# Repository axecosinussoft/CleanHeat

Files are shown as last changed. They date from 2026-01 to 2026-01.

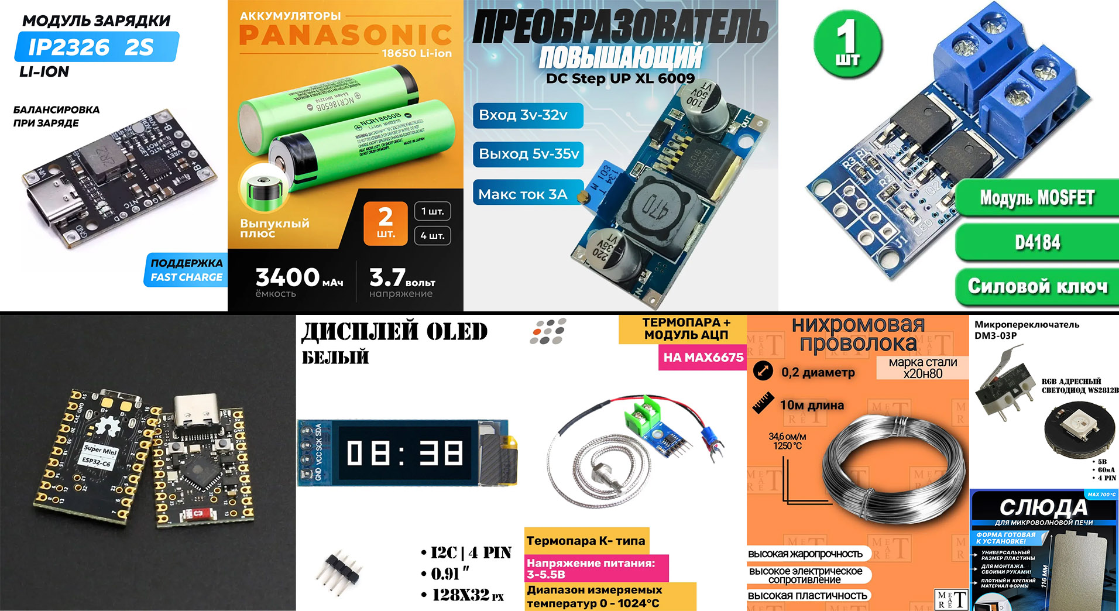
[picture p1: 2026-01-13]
1. 3D Models/1.2 MVP-3 (Jazz)/1.2.3 MVP-3 (Jazz) — Components.jpg

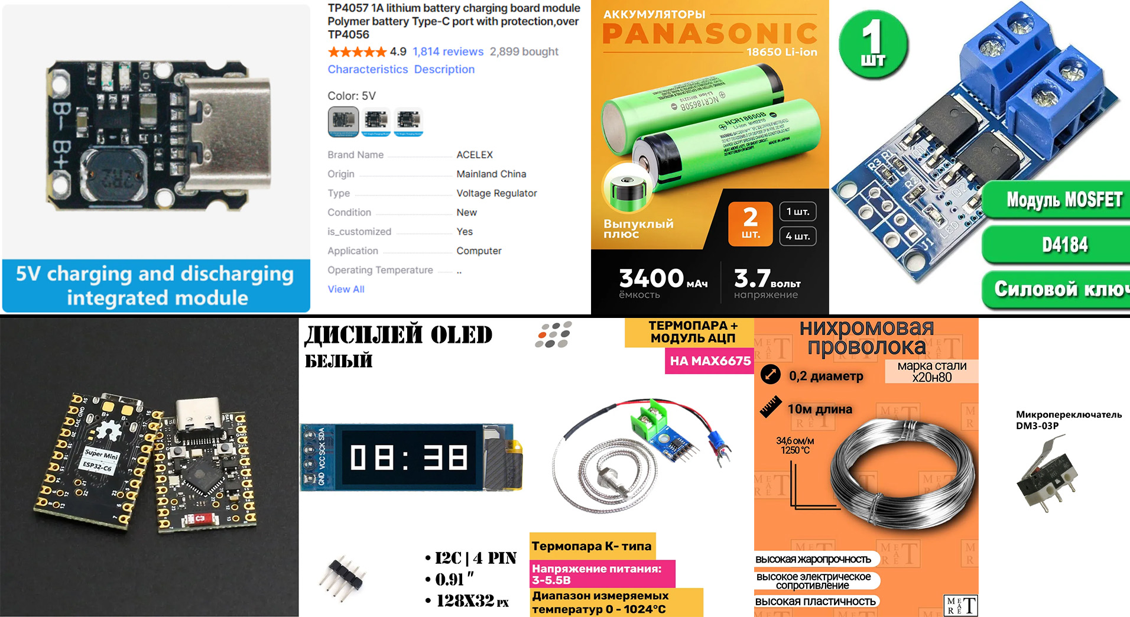
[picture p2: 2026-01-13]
1. 3D Models/1.1 MVP-2 (Slider)/1.1.3 MVP-2 (Slider) — Components.jpg

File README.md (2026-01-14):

Make your own PID controller for heating elements with PWM control and thermocouple feedback, advanced web interface, and smart backlighting.

Tutorial

https://habr.com/ru/articles/973106/

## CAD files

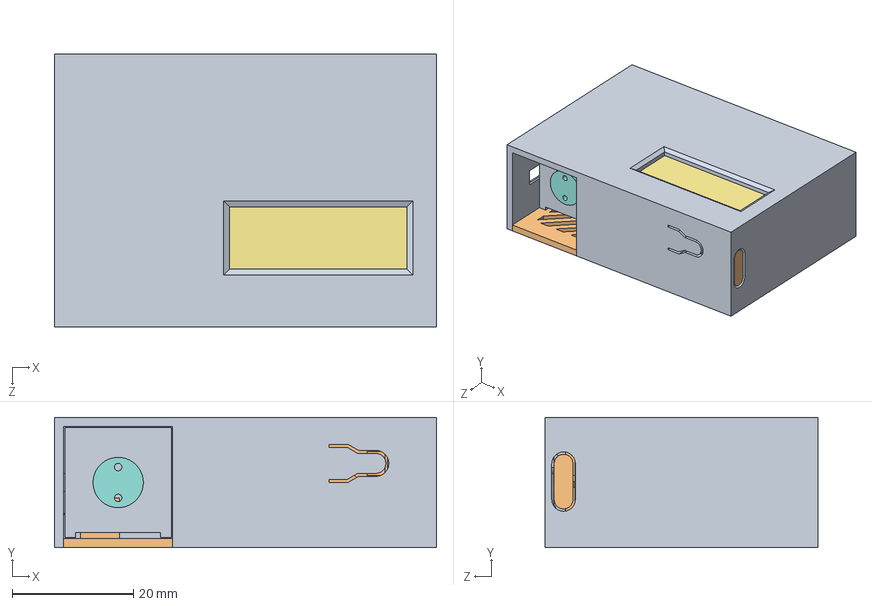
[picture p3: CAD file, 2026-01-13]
1. 3D Models/1.1 MVP-2 (Slider)/1.1.1 3D-Models — SolidWorks 2019/Сборка Clean Heat V7 Charge OLED MAX.SLDASM
63.0 x 21.5 x 45.0 mm
1. Корпус
ESP32-C3-Zero
Battery 16340
Модуль Micro зарядки Type С
MOSFET
MAX6675
OLED 128x32
Патрон нити
2. Каретка патрона
3. Корпус крышка
Кнопка small

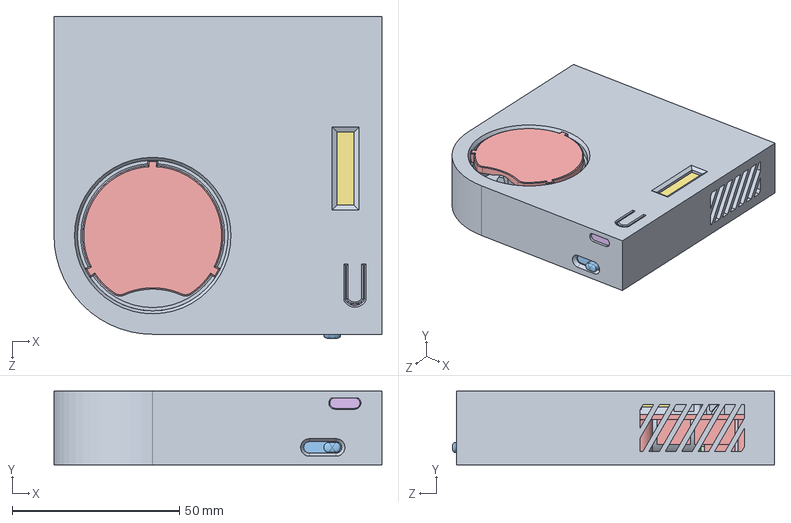
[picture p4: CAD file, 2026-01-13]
1. 3D Models/1.2 MVP-3 (Jazz)/1.2.1 3D-Models — SolidWorks 2019/Сборка Clean Heat V10 — 2S.SLDASM
98.0 x 22.0 x 96.3 mm
1. Корпус
2. Пластина-фиксатор колпака
2.2 Пластина-фиксатор колпака
Колпак
Wire1 x 3
Wire2 x 9
Wire3 x 2
Wire4
Battery 18650 x 2
MAX6675
MOSFET
Charger 2S IP2326
XL6019
ESP32-C3-Zero
OLED 128x32
Кнопка small
3. Подставка микрика
4. Переключатель питания
5. Крышка
LED_WS2812
6. Фиксатор ESP

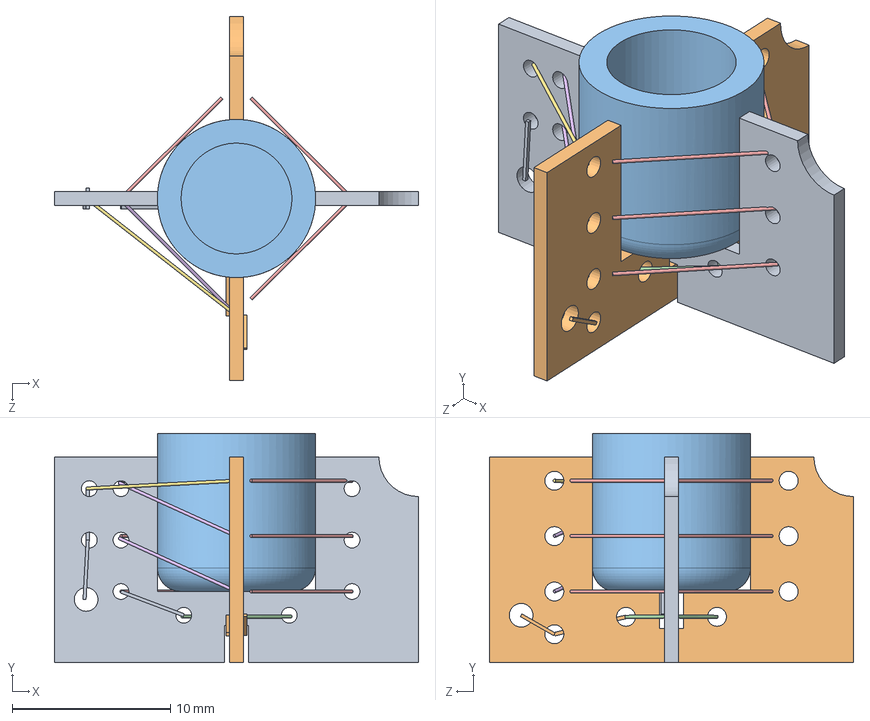
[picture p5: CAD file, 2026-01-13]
1. 3D Models/1.2 MVP-3 (Jazz)/1.2.1 3D-Models — SolidWorks 2019/1. Детали/0.1 Сборка патрона под колпак.SLDASM
23.0 x 14.5 x 23.0 mm
2. Пластина-фиксатор колпака
2.2 Пластина-фиксатор колпака
Колпак
Wire1 x 3
Wire2 x 9
Wire3 x 2
Wire4

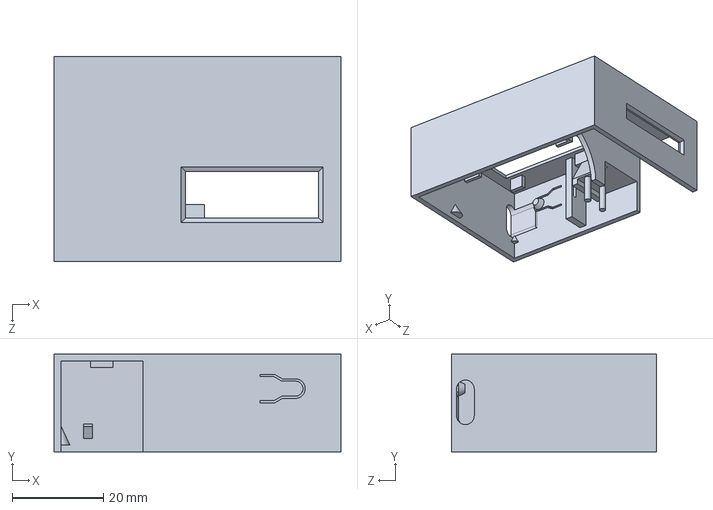
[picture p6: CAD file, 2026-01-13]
1. 3D Models/1.1 MVP-2 (Slider)/1.1.1 3D-Models — SolidWorks 2019/1. Детали/1. Корпус.SLDPRT
63.0 x 21.5 x 45.0 mm

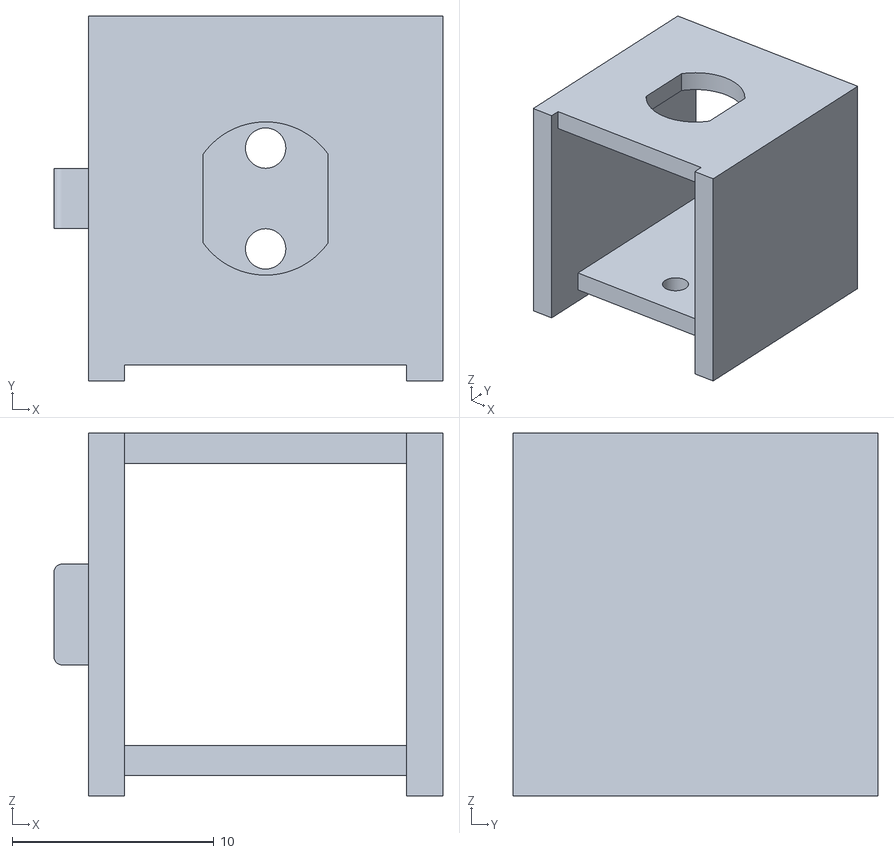
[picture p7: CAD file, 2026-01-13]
1. 3D Models/1.1 MVP-2 (Slider)/1.1.2 3D-Print — STL/2. Каретка патрона — Black.STL
19.3 x 18.1 x 18.0

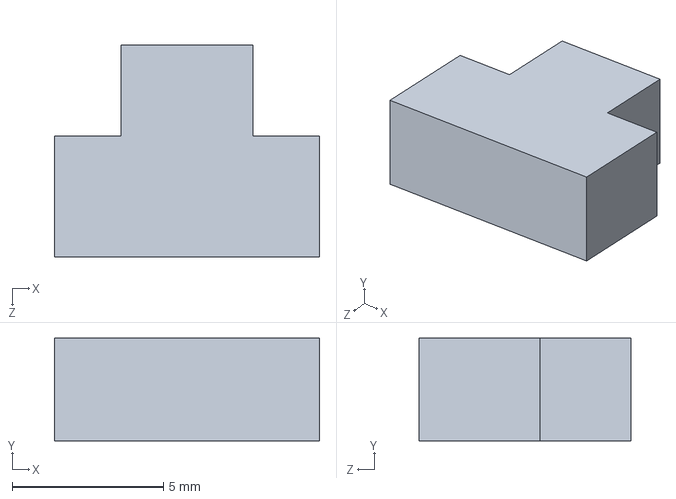
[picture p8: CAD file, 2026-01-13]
1. 3D Models/1.2 MVP-3 (Jazz)/1.2.1 3D-Models — SolidWorks 2019/1. Детали/6. Фиксатор ESP.SLDPRT
8.76 x 3.40 x 7.00 mm

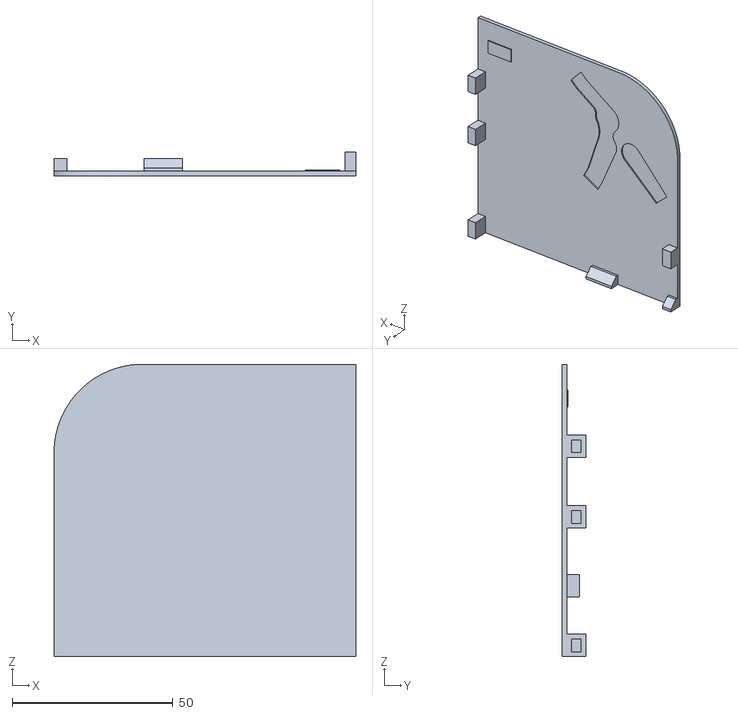
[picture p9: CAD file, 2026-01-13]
1. 3D Models/1.2 MVP-3 (Jazz)/1.2.2 3D-Print — STL/5. Крышка.STL
94.0 x 7.50 x 91.0

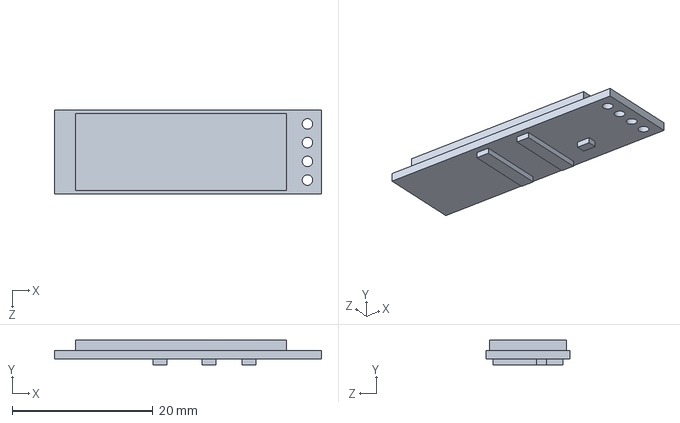
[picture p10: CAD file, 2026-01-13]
1. 3D Models/1.1 MVP-2 (Slider)/1.1.1 3D-Models — SolidWorks 2019/1. Детали/OLED 128x32.SLDPRT
38.0 x 3.50 x 12.0 mm

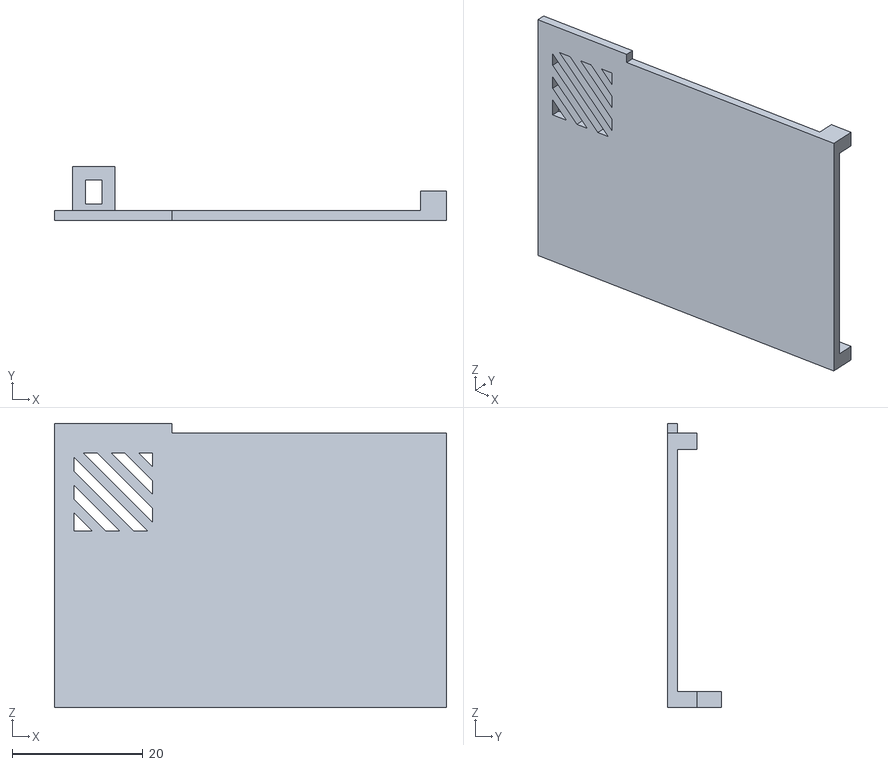
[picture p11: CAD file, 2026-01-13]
1. 3D Models/1.1 MVP-2 (Slider)/1.1.2 3D-Print — STL/3. Корпус крышка — Прозрачный.STL
60.0 x 8.20 x 43.5

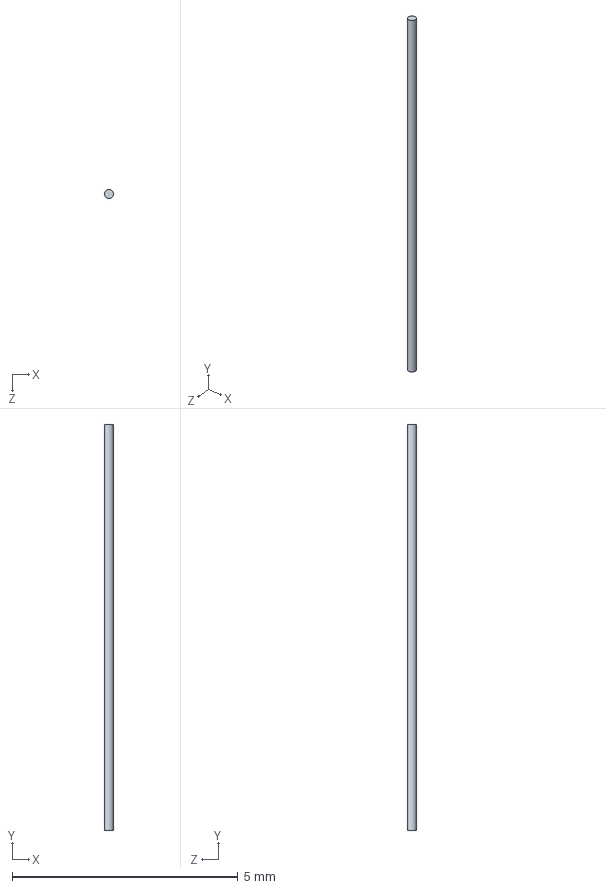
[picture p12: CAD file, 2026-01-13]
1. 3D Models/1.2 MVP-3 (Jazz)/1.2.1 3D-Models — SolidWorks 2019/1. Детали/Wire2.SLDPRT
0.2 x 9.00 x 0.2 mm

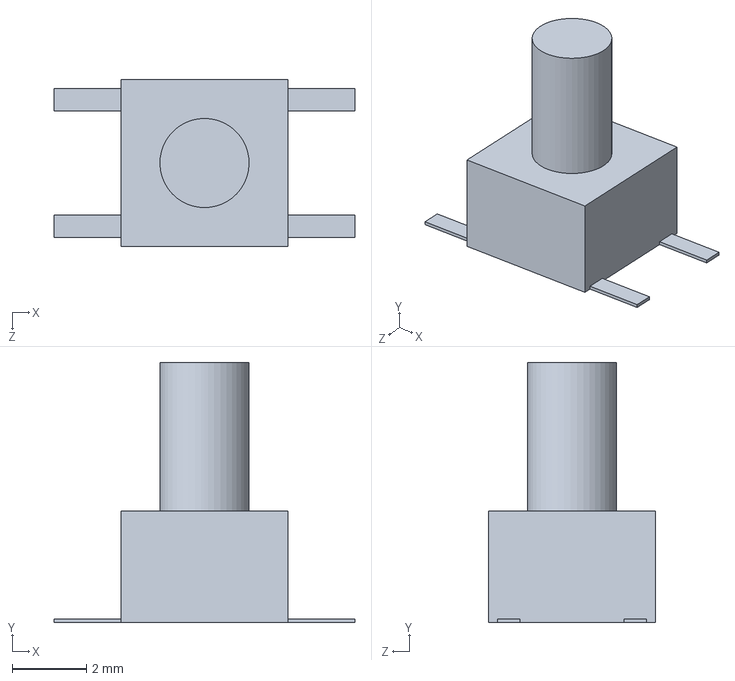
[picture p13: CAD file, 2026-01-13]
1. 3D Models/1.1 MVP-2 (Slider)/1.1.1 3D-Models — SolidWorks 2019/1. Детали/Button.SLDPRT
8.10 x 7.00 x 4.50 mm

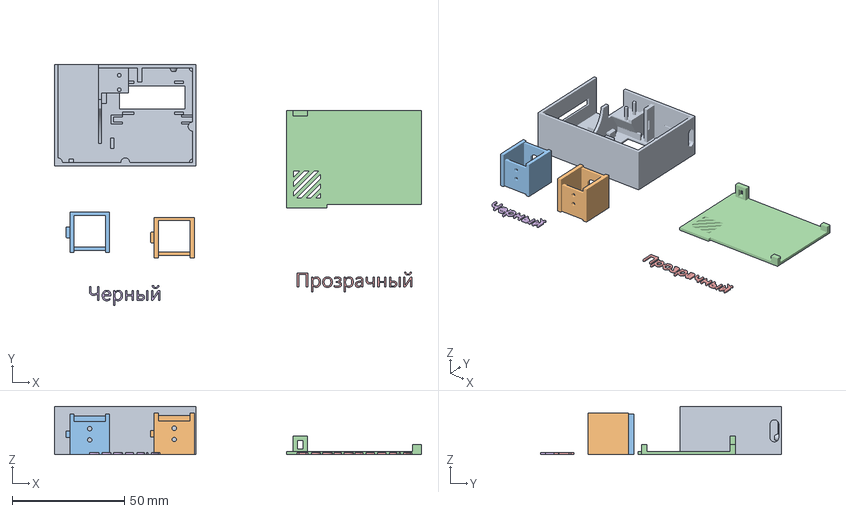
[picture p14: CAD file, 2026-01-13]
1. 3D Models/1.1 MVP-2 (Slider)/1.1.2 3D-Print — STL/2025.06.02 — V1.3mf
163.3 x 107.1 x 21.5 mm
1. Корпус.STL
2. Каретка патрона form.STL
2. Каретка патрона.STL
3. Корпус крышка.STL
Рельефный текст x 2

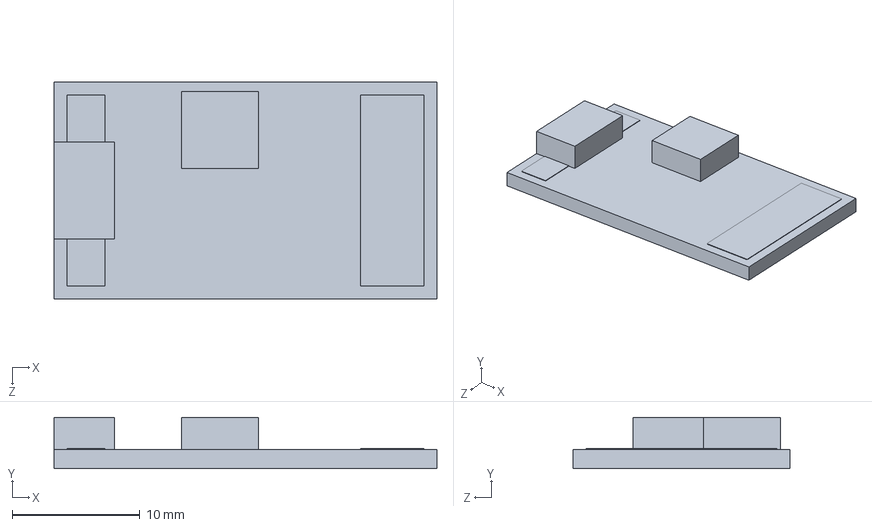
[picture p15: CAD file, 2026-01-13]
1. 3D Models/1.2 MVP-3 (Jazz)/1.2.1 3D-Models — SolidWorks 2019/1. Детали/Charger 2S IP2326.SLDPRT
30.0 x 4.00 x 17.0 mm

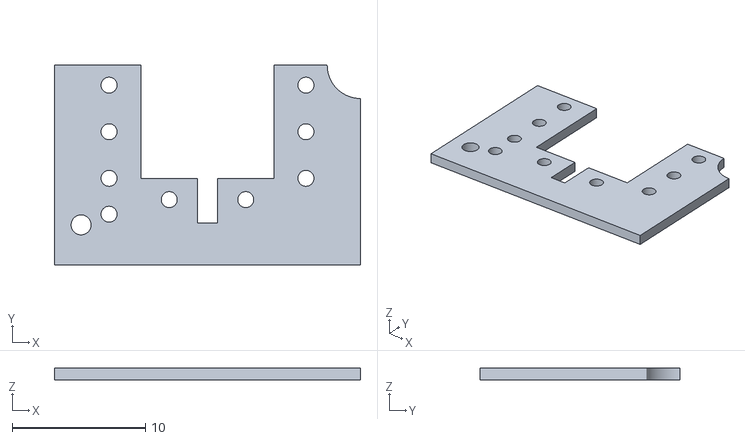
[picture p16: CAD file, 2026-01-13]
1. 3D Models/1.2 MVP-3 (Jazz)/1.2.2 3D-Print — STL/2.2 Пластина-фиксатор колпака.STL
23.0 x 15.0 x 0.9

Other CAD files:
1. 3D Models/1.2 MVP-3 (Jazz)/1.2.2 3D-Print — STL/6. Фиксатор ESP.STL
1. 3D Models/1.1 MVP-2 (Slider)/1.1.1 3D-Models — SolidWorks 2019/1. Детали/Модуль Micro зарядки Type С.SLDPRT
1. 3D Models/1.1 MVP-2 (Slider)/1.1.2 3D-Print — STL/2. Каретка патрона form — Black.STL
1. 3D Models/1.2 MVP-3 (Jazz)/1.2.1 3D-Models — SolidWorks 2019/1. Детали/Wire3.SLDPRT
1. 3D Models/1.1 MVP-2 (Slider)/1.1.1 3D-Models — SolidWorks 2019/1. Детали/2. Каретка патрона.SLDPRT
1. 3D Models/1.1 MVP-2 (Slider)/1.1.1 3D-Models — SolidWorks 2019/1. Детали/3. Корпус крышка.SLDPRT
1. 3D Models/1.1 MVP-2 (Slider)/1.1.1 3D-Models — SolidWorks 2019/1. Детали/Battery 14500.SLDPRT
1. 3D Models/1.1 MVP-2 (Slider)/1.1.1 3D-Models — SolidWorks 2019/1. Детали/Battery 16340.SLDPRT
1. 3D Models/1.1 MVP-2 (Slider)/1.1.1 3D-Models — SolidWorks 2019/1. Детали/ESP32-C3-Zero.SLDPRT
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

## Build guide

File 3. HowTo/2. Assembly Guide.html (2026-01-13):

# 🔥 Clean Heat Controller

Firmware v1.0.65 | Инструкция по сборке

## 📦 Список компонентов

ESP32-C3 Super Mini

Микроконтроллер с WiFi, 4MB Flash

OLED Дисплей 0.91"

128×32 пикселей, I2C (SSD1306)

MAX6675 + K-термопара

Модуль АЦП для термопары, 0-1024°C

MOSFET D4184

Силовой ключ для нагревателя

TP4056/TP4057 модуль

Зарядка Li-ion через Type-C

2× 18650 Panasonic

Li-ion 3400mAh, соединены последовательно

Нихромовая проволока

0.2мм, X20H80, нагревательный элемент

WS2812B LED

Адресный RGB светодиод

Микропереключатель

DM3-03P, кнопка управления

Резисторы

100K + 56K (делитель напряжения)

## 📐 Схема подключения

Принципиальная схема Clean Heat Controller

## 🔌 Таблица подключений

ESP32-C3 Pin | Подключение | Функция | Цвет провода
GPIO0 | MAX6675 → DO | SPI Data Out (термопара) | Зелёный
GPIO1 | MAX6675 → CS | SPI Chip Select | Оранжевый
GPIO2 | MAX6675 → CLK | SPI Clock | Фиолетовый
GPIO3 | Делитель напряжения | ADC измерение батареи | Голубой
GPIO4 | MOSFET D4184 → SIG | PWM управление нагревателем | Красный
GPIO6 | OLED → SDA | I2C Data | Красный
GPIO7 | OLED → SCL | I2C Clock | Синий
GPIO8 | WS2812B → DIN | Адресный LED данные | Зелёный
GPIO9 | Кнопка → SIG | Вход кнопки (INPUT_PULLUP) | Сиреневый
3V3 | MAX6675, OLED, WS2812B → VCC | Питание 3.3В | Красный
GND | Все модули → GND | Общая земля | Чёрный

## 🔧 Делитель напряжения

## 📝 Пошаговая сборка

1 Подготовка батарейного отсека

Соедините два аккумулятора 18650 последовательно (+ первого к - второго). Общее напряжение: 6.0-8.4В.

2 Делитель напряжения

Спаяйте резисторы 100K и 56K последовательно. Точка соединения идёт на GPIO3. Верхний конец (100K) к B+, нижний (56K) к GND.

3 MAX6675 термопара

Подключите модуль: DO→GPIO0, CS→GPIO1, CLK→GPIO2, VCC→3V3, GND→GND. Припаяйте термопару к модулю.

4 OLED дисплей

Подключите по I2C: SDA→GPIO6, SCL→GPIO7, VCC→3V3, GND→GND.

5 MOSFET и нагреватель

SIG→GPIO4, VCC модуля→B+ батареи, GND→GND. Выход MOSFET (OUT+/OUT-) к нихромовой проволоке.

6 WS2812B LED

DIN→GPIO8, VCC→3V3, GND→GND.

7 Кнопка управления

Один контакт→GPIO9, второй→GND. Внутренний pull-up включён в коде.

8 Зарядка TP4056

B+→плюс батареи, B-→минус батареи. Модуль обеспечивает зарядку через Type-C.

⚠️ Важные предупреждения

• Перед первым включением проверьте все соединения мультиметром
• Не замыкайте выходы батареи — риск возгорания
• Нихромовая проволока нагревается до 350°C — соблюдайте осторожность
• Не оставляйте устройство без присмотра во время нагрева

💡 Рекомендации

• Используйте провода сечением минимум 22AWG для силовых цепей
• Термопару располагайте максимально близко к нагревателю
• Обеспечьте теплоотвод для MOSFET при длительной работе
• Перед прошивкой отключите питание от батареи

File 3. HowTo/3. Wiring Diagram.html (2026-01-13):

# Clean Heat Controller

Схема подключения компонентов

VCC / V+ / 3V3 / VIN

GND

DO / DIN / ADC

CS / SDA

CLK / SCL

PWM / SIG / OUT

Button

### Таблица подключений

GPIO 0MAX6675 DO

GPIO 1MAX6675 CS

GPIO 2MAX6675 CLK

GPIO 3Battery ADC (Divider)

GPIO 4MOSFET PWM

GPIO 6OLED SDA

GPIO 7OLED SCL

GPIO 8WS2812B DIN

GPIO 9Button → GND

3V3Logic VCC (3.3V)

VINBattery Input (7.4V)

GNDCommon Ground

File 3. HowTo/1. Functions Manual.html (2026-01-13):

# Clean Heat Controller

Руководство по функциям и управлению • Версия прошивки 1.0.63

## Обзор устройства

Clean Heat Controller — температурный контроллер на базе ESP32-C3 с PID-регулированием, веб-интерфейсом и RGB индикацией. Устройство предназначено для точного управления нагревательными элементами.

PID-регулирование

Адаптивный алгоритм с агрессивным и консервативным режимами для точного поддержания температуры

WiFi управление

Встроенная точка доступа с captive portal и веб-интерфейсом

Мониторинг АКБ

Отслеживание напряжения и процента заряда 2S Li-ion аккумулятора

RGB индикация

Цветовая индикация режимов, температуры и состояния

## Управление кнопкой

Одиночное нажатие

Переключение температурного режима: OFF → Mode 1 → Mode 2 → Mode 3 → MAX → OFF. При пользовательском режиме (PWM или Custom Temp) — переход в OFF.

Двойное нажатие

Переключение режима LED: OFF → TEMP → FLOW → OFF. На экране появляется уведомление о текущем режиме.

Тройное нажатие

Управление таймером: пауза таймера (если запущен) или сброс (если на паузе). Таймер мигает при действии.

Долгое нажатие (1 сек)

Переход в режим ожидания сна. Экран инвертируется, полоска внизу анимированно уменьшается. Нагрев отключается, LED выключается. Если не нажать кнопку в течение 5 секунд — устройство уйдёт в глубокий сон.

## Температурные режимы

Режим | Температура | Описание
OFF | — | Нагрев выключен, PWM = 0%
Mode 1 | 210°C * | Первый предустановленный режим
Mode 2 | 220°C * | Второй предустановленный режим
Mode 3 | 240°C * | Третий предустановленный режим
MAX | 100% PWM | Максимальная мощность без регулирования

* Настраиваемые значения
Температуры режимов Mode 1, Mode 2, Mode 3 можно изменить через веб-интерфейс. Значения сохраняются в энергонезависимой памяти. Диапазон: 50–350°C. По умолчанию: 210 / 220 / 240°C.

### Дополнительные режимы (через веб-интерфейс)

Режим | Описание
Custom Temp | Произвольная температура с PID-регулированием (кнопки ±1°C и ±5°C)
Custom PWM | Прямое управление мощностью 0–100% без PID-регулирования

## Дисплей

Дисплей SSD1306 128×32 пикселей в портретной ориентации отображает всю ключевую информацию:

### Элементы дисплея

Целевая температура Инвертированный блок с текущим режимом

Текущая температура Значение с термопары в °C

PWM мощность OFF или 0–100%

Счётчик циклов Количество завершённых сессий нагрева

WiFi индикатор Точка внизу = клиент подключен

Таймер MM:SS с момента начала нагрева

Линия предупреждения Анимированно исчезает перед сном

## LED индикация

LED OFF

Светодиод выключен

LED TEMP

Цвет отражает температуру или PWM:
Синий → Зелёный → Жёлтый → Оранжевый → Красный → Розовый
В режиме MAX — пульсация красный/оранжевый

LED FLOW

Плавная радужная анимация с периодическими вспышками. Параметры настраиваются через Serial.

### Специальные состояния LED

Загрузка устройства Радужная анимация 1.7 сек

Вкладка Update активна Плавная пульсация синий ↔ фиолетовый

OTA обновление Мигание красный / синий

OTA успешно Фиолетовые вспышки → перезагрузка

## WiFi и веб-интерфейс

### Подключение

Имя сети (SSID) Clean Heat

Пароль Отсутствует (открытая сеть)

Captive Portal Автоматическое перенаправление

### Функции веб-интерфейса

Управление режимами

Быстрые кнопки OFF / Mode 1 / Mode 2 / Mode 3 / MAX

Точная настройка температуры

Кнопки ±1°C и ±5°C для пользовательской температуры

PWM управление

Слайдер 0–100% для прямого управления мощностью

Сохранение режимов

Запись текущей температуры в Mode 1/2/3

Управление таймером

Пауза и сброс таймера сессии

Счётчик циклов

Просмотр, коррекция (±1) и сброс счётчика

Мониторинг

Температура, PWM, напряжение АКБ в реальном времени

OTA обновление

Загрузка новой прошивки через браузер

Темы оформления

Светлая и тёмная тема интерфейса

## API эндпоинты

GET /status JSON со всеми параметрами устройства

GET /set_temp?mode=0-4 Установка режима (0=OFF, 1-3=Mode, 4=MAX)

GET /adjust_temp?delta=±N Изменение температуры на N градусов

GET /set_pwm?value=0-100 Установка PWM в процентах

GET /pwm_adjust?delta=±N Изменение PWM на N процентов

GET /save_mode_temp?mode=1-3 Сохранение текущей температуры в режим

GET /timer_pause Пауза/возобновление таймера

GET /timer_reset Сброс таймера

GET /cycle_adjust?delta=±1 Изменение счётчика циклов

GET /cycle_reset Сброс счётчика циклов

GET /set_led_mode?mode=0-2 Режим LED (0=OFF, 1=TEMP, 2=FLOW)

GET /toggle_led Переключение LED вкл/выкл

GET /set_theme?dark=true|false Установка темы интерфейса

POST /update OTA загрузка прошивки (multipart/form-data)

## Serial команды (LED Flow)

Настройка параметров режима LED FLOW через Serial Monitor (115200 baud):

flow_settings

Показать текущие настройки

flow_speed <10-200>

Скорость смены цвета радуги (по умолчанию: 50)

flow_pulse_min <3000-30000>

Минимальный интервал между вспышками в мс (по умолчанию: 5000)

flow_pulse_max <5000-60000>

Максимальный интервал между вспышками в мс (по умолчанию: 15000)

flow_pulse_duration <200-2000>

Длительность одной вспышки в мс (по умолчанию: 800)

flow_pulse_count <1-10>

Максимальное количество вспышек подряд (по умолчанию: 3)

flow_help

Справка по командам

## Автоматические функции

### Auto Sleep

Устройство автоматически переходит в режим ожидания сна если:

- Нагрев выключен
- Нет подключенных WiFi клиентов
- Прошло 30 секунд без активности (или 120 сек если LED включен)

### Счётчик циклов нагрева

Цикл засчитывается если:

- Нагрев был активен минимум 20 секунд
- Начальная температура была ниже 80°C (исключает "продолжение")

### PID-регулятор

Агрессивный режим (ошибка > 10°C) Kp=8.0, Ki=0.5, Kd=2.0

Консервативный режим (ошибка ≤ 10°C) Kp=3.0, Ki=0.2, Kd=1.0

Коррекция температуры +15°C к целевой (TEMP_CORRECTION)

Допуск стабильности ±2°C (TEMP_TOLERANCE)

## Технические параметры

### Питание

Напряжение АКБ 6.0 – 8.4V (2S Li-ion)

Делитель напряжения ×2.782

### Измерения

Обновление температуры Каждые 500 мс

Обновление напряжения Каждые 2000 мс (10 сэмплов)

Обновление PID Каждые 200 мс

### Управление

PWM частота 1000 Hz

PWM разрешение 8 бит (0-255)

Debounce кнопки 50 мс

Долгое нажатие 1000 мс

Таймаут двойного клика 500 мс

### Sleep

Предупреждение перед сном 5 секунд

Auto Sleep (LED выключен) 30 секунд

Auto Sleep (LED включен) 120 секунд

Clean Heat Controller v1.0.63 • Руководство по функциям

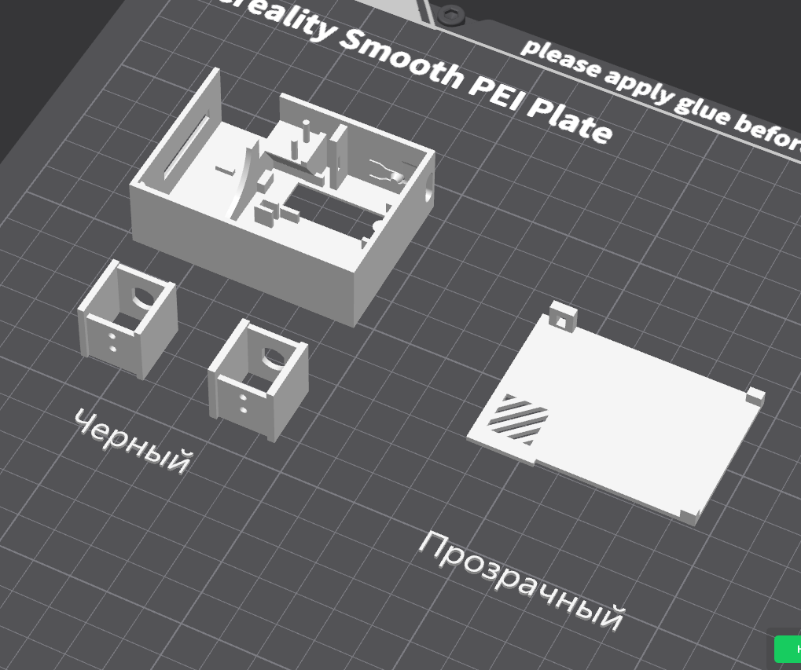
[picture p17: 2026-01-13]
1. 3D Models/1.1 MVP-2 (Slider)/1.1.2 3D-Print — STL/Place.png

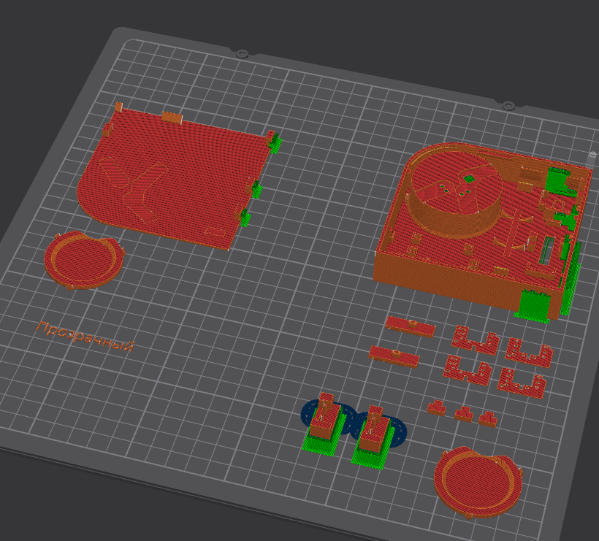
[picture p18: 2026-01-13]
1. 3D Models/1.2 MVP-3 (Jazz)/1.2.2 3D-Print — STL/2025.07.08 — V10 (2S).png

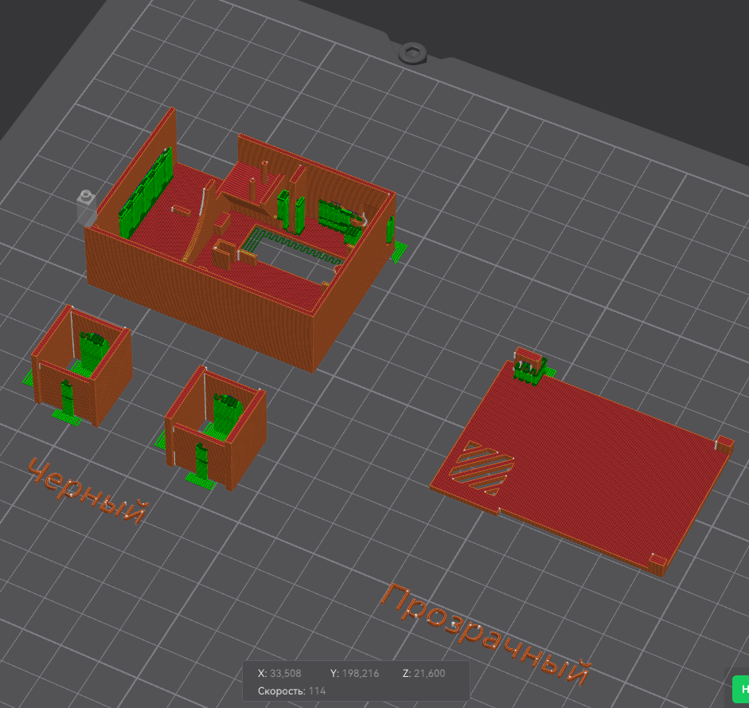
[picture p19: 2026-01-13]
1. 3D Models/1.1 MVP-2 (Slider)/1.1.2 3D-Print — STL/Поддержки.png

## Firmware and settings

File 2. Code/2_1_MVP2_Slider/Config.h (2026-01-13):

#ifndef CONFIG_H
#define CONFIG_H

#define FIRMWARE_VERSION "1.0.65"

extern int MODE_1_TEMP;
extern int MODE_2_TEMP;
extern int MODE_3_TEMP;

#define DEFAULT_MODE_1_TEMP 210
#define DEFAULT_MODE_2_TEMP 220
#define DEFAULT_MODE_3_TEMP 240

#define TEMP_CORRECTION 15.0

#define SCREEN_WIDTH 128
#define SCREEN_HEIGHT 32
#define SDA_PIN 6
#define SCL_PIN 7
#define SCREEN_ADDRESS 0x3C

#define MAX_CLK_PIN 2
#define MAX_CS_PIN  1
#define MAX_DO_PIN  0

#define BUTTON_PIN 9
#define HEATER_PIN 3
#define BATTERY_PIN 4

#define LED_PIN 8
#define NUM_LEDS 1
#define LED_BRIGHTNESS 200

#define PWM_FREQ 1000
#define PWM_RESOLUTION 8
#define PWM_CHANNEL 0

#define VOLTAGE_DIVIDER_FACTOR 3.15
#define ADC_REFERENCE_VOLTAGE 3.3
#define ADC_RESOLUTION 4095.0
#define BATTERY_MIN_VOLTAGE 3.0
#define BATTERY_MAX_VOLTAGE 4.2

#define VOLTAGE_FILTER_ALPHA 0.1
#define VOLTAGE_SAMPLES 10
#define VOLTAGE_SAMPLE_INTERVAL 10

#define TEMP_UPDATE_INTERVAL 500
#define VOLTAGE_UPDATE_INTERVAL 2000
#define DEBOUNCE_DELAY 50
#define INIT_DELAY 500
#define LONG_PRESS_DURATION 1000
#define DOUBLE_CLICK_TIMEOUT 500
#define FLASH_DURATION 100

#define PID_UPDATE_INTERVAL 200
#define TEMP_TOLERANCE 2.0

#define KP_AGGRESSIVE 8.0
#define KI_AGGRESSIVE 0.5
#define KD_AGGRESSIVE 2.0

#define KP_CONSERVATIVE 3.0
#define KI_CONSERVATIVE 0.2
#define KD_CONSERVATIVE 1.0

#define TEMP_GAP_THRESHOLD 10.0
#define INTEGRAL_WINDUP_LIMIT 50.0
#define DERIVATIVE_FILTER_ALPHA 0.3

#define SLEEP_WARNING_DURATION 5000
#define BATTERY_BLINK_INTERVAL 600
#define SCREEN_FLASH_DURATION 100
#define WAKE_BUTTON_BLOCK_TIME 500

#define AUTO_SLEEP_TIMEOUT 30000
#define AUTO_SLEEP_TIMEOUT_LED_ACTIVE 120000

#define CYCLE_COUNT_THRESHOLD 20000
#define CYCLE_CONTINUATION_TEMP_THRESHOLD 80.0

#define LED_FLOW_DEFAULT_SPEED 50
#define LED_FLOW_DEFAULT_PULSE_MIN_INTERVAL 5000
#define LED_FLOW_DEFAULT_PULSE_MAX_INTERVAL 15000
#define LED_FLOW_DEFAULT_PULSE_DURATION 800
#define LED_FLOW_DEFAULT_PULSE_COUNT 3

extern const char* ssid;
extern const byte DNS_PORT;

extern DNSServer dnsServer;
extern AsyncWebServer server;
extern Adafruit_SSD1306 display;
extern MAX6675 thermocouple;
extern Preferences prefs;

enum TempMode { TEMP_OFF, TEMP_200, TEMP_220, TEMP_240, TEMP_MAX };
extern TempMode currentTempMode;
extern bool isCustomPWM;
extern int customPWMValue;
extern int currentCustomTemp;

enum LEDMode { LED_OFF, LED_TEMP, LED_FLOW };
extern LEDMode currentLEDMode;

extern const float targetTemps[5];
extern const String tempLabels[5];

struct PIDData {
  float kp, ki, kd;
  float lastError;
  float integral;
  float lastTemp;
  float filteredDerivative;
  bool isStable;
  int stableCount;
  unsigned long lastTime;
};

extern PIDData pid;

extern float temperature;
extern float batteryVoltage;
extern float filteredVoltage;
extern int batteryPercent;

extern bool timerRunning;
extern bool timerPaused;
extern unsigned long timerStartMillis;
extern unsigned long timerPausedTime;
extern unsigned long timerElapsed;
extern unsigned long lastDisplayMillis;
extern bool timerFlashActive;
extern unsigned long timerFlashStart;
extern bool screenFlashActive;
extern unsigned long screenFlashStart;

extern int lastButtonState;
extern int buttonState;
extern unsigned long lastDebounceTime;
extern unsigned long buttonPressTime;
extern unsigned long buttonReleaseTime;
extern bool longPressHandled;
extern bool waitingForDoubleClick;
extern unsigned long firstClickTime;
extern int clickCount;
extern bool waitingForMultiClick;
extern unsigned long lastClickTime;

extern unsigned long previousTempMillis;
extern unsigned long previousVoltageMillis;
extern unsigned long voltageSampleMillis;
extern int voltageSampleIndex;
extern float voltageSampleSum;
extern bool voltageReadingActive;
extern unsigned long initStartTime;
extern bool isInitialized;

extern int pidOutput;

extern bool sleepWarningActive;
extern unsigned long sleepWarningStart;
extern volatile bool batteryBlinkState;
extern unsigned long lastBatteryBlink;
extern bool anyButtonPressed;

extern bool wakeFromSleepFlag;
extern unsigned long wakeTime;
extern bool resetTimerAfterSleep;

extern unsigned long lastActivityTime;

extern int heatCycleCount;
extern bool heatingActive;
extern bool cycleCounted;
extern unsigned long heatingStartTime;
extern bool isCycleContinuation;

#include <FastLED.h>
extern CRGB leds[NUM_LEDS];
extern unsigned long lastLedUpdate;
extern unsigned long ledTransitionStart;
extern bool ledTransitioning;
extern CRGB ledCurrentColor;
extern CRGB ledTargetColor;
extern bool ledForceDisabled;
extern bool bootRainbowActive;
extern unsigned long bootRainbowStart;
extern bool ledToggleTransition;

extern unsigned long ledFlowStartTime;
extern float ledFlowHue;
extern unsigned long ledFlowPulseStart;
extern bool ledFlowPulseActive;
extern int ledFlowPulseCount;
extern int ledFlowPulseTarget;
extern unsigned long ledFlowNextPulse;
extern int ledFlowSpeed;
extern int ledFlowPulseMinInterval;
extern int ledFlowPulseMaxInterval;
extern int ledFlowPulseDuration;
extern int ledFlowPulseMaxCount;

extern bool otaInProgress;
extern bool otaSuccess;
extern unsigned long otaStartTime;
extern unsigned long otaLedUpdate;
extern bool otaLedState;
extern int otaBlinkCount;
extern unsigned long otaBlinkStart;
extern bool otaBlinkPhase;

extern bool updateTabActive;
extern unsigned long lastUpdateTabActivity;
extern CRGB otaWaitColor1;
extern CRGB otaWaitColor2;
extern unsigned long otaTransitionStart;
extern CRGB otaCurrentColor;

extern bool notificationActive;
extern unsigned long notificationStart;
extern String notificationText1;
extern String notificationText2;

extern int previousWiFiClients;
extern bool isDarkTheme;

void loadThemeSettings();
void saveThemeSettings();
void setTheme(bool dark);

static const unsigned char PROGMEM wifi_bitmap_12[] = {
  0x00, 0x00, 0x1F, 0x80, 0x60, 0x60, 0x80, 0x10, 0x0F, 0x00, 0x30, 0xC0, 
  0x40, 0x20, 0x0F, 0x00, 0x10, 0x80, 0x00, 0x00, 0x06, 0x00, 0x06, 0x00
};

static const unsigned char PROGMEM battery_bitmap[] = {
  0x7F, 0xFF, 0x00, 0x40, 0x01, 0x80, 0x40, 0x01, 0x80, 0x40, 0x01, 0x80,
  0x40, 0x01, 0x80, 0x40, 0x01, 0x80, 0x40, 0x01, 0x80, 0x7F, 0xFF, 0x00
};

void initHeatCycleCounter();
void updateHeatCycleCounter();
void saveHeatCycleCount();
void resetHeatCycleCount();
void adjustHeatCycleCount(int delta);
void updateLastActivity();
void checkAutoSleep();
float getActualTargetTemp(TempMode mode);
void initPID();
void updatePID();
void setTempMode(TempMode mode);
void setCustomTemp(int temp);
void startTimer();
void pauseTimer();
void resetTimer();
void resumeTimerIfPaused();
void handleSingleClick();
void handleDoubleClick();
void handleTripleClick();
void handleLongPress();
void handleSleepWarning();
void goToSleep();
void handleButton();
void startVoltageReading();
void processVoltageSample();
void updateBatteryVoltage();
int calculateBatteryPercent(float voltage);
void setPWMByPercent(int percent);
void loadTempSettings();
void saveTempSettings();
void setModeTemp(int mode, int temp);
int getCurrentTargetTemp();

void setupWebServer();
String generateWebPage();
void updateDisplay();
void updateLED();
void setLEDMode();
void setLEDModeType(LEDMode mode);
void toggleLEDForceState();
void initLEDFlow();
void updateLEDFlow();
void startOTA();
void handleOTAProgress();
void handleOTASuccess();
void checkUpdateTabActivity();
void setUpdateTabActive();
void clearUpdateTabMode();
void showNotification(String line1, String line2);
void updateNotification();
void checkWiFiClients();
void processSerialCommands();
void loadLEDFlowSettings();
void saveLEDFlowSettings();

#endif

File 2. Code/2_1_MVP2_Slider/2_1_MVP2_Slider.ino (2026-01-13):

#include <WiFi.h>
#include <AsyncTCP.h>
#include <ESPAsyncWebServer.h>
#include <DNSServer.h>
#include <Wire.h>
#include <Adafruit_GFX.h>
#include <Adafruit_SSD1306.h>
#include <max6675.h>
#include <esp_sleep.h>
#include <Preferences.h>
#include <FastLED.h>
#include <Update.h>

#include "Config.h"
#include "Functions.h"
#include "Display.h"
#include "UI.h"

void setup() {
  Serial.begin(115200);
  analogReadResolution(12);
  analogSetAttenuation(ADC_11db);
  
  pinMode(HEATER_PIN, OUTPUT);
  digitalWrite(HEATER_PIN, LOW);
  pinMode(BUTTON_PIN, INPUT_PULLUP);
  pinMode(BATTERY_PIN, INPUT);

  buttonState = digitalRead(BUTTON_PIN);
  lastButtonState = buttonState;

  esp_sleep_enable_gpio_wakeup();

  ledcSetup(PWM_CHANNEL, PWM_FREQ, PWM_RESOLUTION);
  ledcAttachPin(HEATER_PIN, PWM_CHANNEL);
  ledcWrite(PWM_CHANNEL, 0);

  Wire.begin(SDA_PIN, SCL_PIN);
  if (!display.begin(SSD1306_SWITCHCAPVCC, SCREEN_ADDRESS)) {
    while (true);
  }

  FastLED.addLeds<WS2812B, LED_PIN, GRB>(leds, NUM_LEDS);
  FastLED.setBrightness(LED_BRIGHTNESS);
  FastLED.clear();
  FastLED.show();
  bootRainbowStart = millis();

  display.setRotation(1);
  display.clearDisplay();
  display.setTextSize(1);
  display.setTextColor(SSD1306_WHITE);
  display.setCursor(0, 0);
  display.println("TEMP CONTROLLER");
  display.println("Initializing...");
  display.display();

  loadTempSettings();
  loadThemeSettings();
  loadLEDFlowSettings();

  WiFi.softAP(ssid);
  dnsServer.start(DNS_PORT, "*", WiFi.softAPIP());
  setupWebServer();
  server.begin();

  float initialVoltage = analogRead(BATTERY_PIN);
  initialVoltage = (initialVoltage / ADC_RESOLUTION) * ADC_REFERENCE_VOLTAGE * VOLTAGE_DIVIDER_FACTOR;
  filteredVoltage = initialVoltage;
  batteryVoltage = initialVoltage;

  initPID();
  initHeatCycleCounter();
  initLEDFlow();
  initStartTime = millis();
  lastActivityTime = millis();
  previousWiFiClients = 0;
  
  Serial.println("=== Clean Heat Controller Started ===");
  Serial.println("Version: " + String(FIRMWARE_VERSION));
  Serial.println("Type 'flow_help' for LED Flow commands");
}

void loop() {
  unsigned long currentMillis = millis();
  
  dnsServer.processNextRequest();
  processSerialCommands();
  
  updateLED();

  if (timerFlashActive && (currentMillis - timerFlashStart >= FLASH_DURATION)) {
    timerFlashActive = false;
    updateDisplay();
  }

  if (screenFlashActive && (currentMillis - screenFlashStart >= SCREEN_FLASH_DURATION)) {
    screenFlashActive = false;
    updateDisplay();
  }

  if (waitingForDoubleClick && (currentMillis - firstClickTime >= DOUBLE_CLICK_TIMEOUT)) {
    waitingForDoubleClick = false;
    handleSingleClick();
  }

  if (!isInitialized && (currentMillis - initStartTime >= INIT_DELAY)) {
    isInitialized = true;
    updateDisplay();
  }

  if (sleepWarningActive) {
    handleSleepWarning();
    
    if (currentMillis - previousTempMillis >= TEMP_UPDATE_INTERVAL) {
      previousTempMillis = currentMillis;
      temperature = thermocouple.readCelsius();
      Serial.print("Temp update: "); Serial.println(temperature);
      updateDisplay();
    }
    
    if (currentMillis - lastBatteryBlink >= BATTERY_BLINK_INTERVAL) {
      Serial.print("Before toggle - batteryBlinkState: "); Serial.println(batteryBlinkState);
      if (batteryBlinkState) {
        batteryBlinkState = false;
        Serial.println("Setting to FALSE");
      } else {
        batteryBlinkState = true;
        Serial.println("Setting to TRUE");
      }
      lastBatteryBlink = currentMillis;
      Serial.print("After toggle - batteryBlinkState: "); Serial.print(batteryBlinkState ? "ON" : "OFF");
      Serial.print(" ("); Serial.print(batteryBlinkState); Serial.print(")");
      Serial.print(" at millis: "); Serial.println(currentMillis);
      updateDisplay();
    }
    return;
  }

  if (otaInProgress) {
    if (currentMillis - previousTempMillis >= TEMP_UPDATE_INTERVAL) {
      previousTempMillis = currentMillis;
      temperature = thermocouple.readCelsius();
      updateDisplay();
    }
    return;
  }

  if (isInitialized) {
    handleButton();
    checkAutoSleep();
    updateHeatCycleCounter();
    checkUpdateTabActivity();
    updateNotification();
    checkWiFiClients();

    if (currentMillis - previousTempMillis >= TEMP_UPDATE_INTERVAL) {
      previousTempMillis = currentMillis;
      temperature = thermocouple.readCelsius();
      updatePID();
      updateDisplay();
    }

    if (currentMillis - previousVoltageMillis >= VOLTAGE_UPDATE_INTERVAL && !voltageReadingActive) {
      previousVoltageMillis = currentMillis;
      startVoltageReading();
    }
    
    if (voltageReadingActive) {
      processVoltageSample();
    }

    if (timerRunning && !timerPaused && (currentMillis - lastDisplayMillis >= 1000)) {
      lastDisplayMillis = currentMillis;
      updateDisplay();
    }
  }
}
